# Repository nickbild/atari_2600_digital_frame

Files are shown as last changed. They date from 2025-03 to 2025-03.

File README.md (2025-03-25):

# Atari 2600 Digital Photo Frame

Turn your family photos into retro 8-bit masterpieces with this Atari 2600 digital frame. It is powered by a custom cartridge containing a Raspberry Pi Pico, so it can do a lot of other tricks as well.

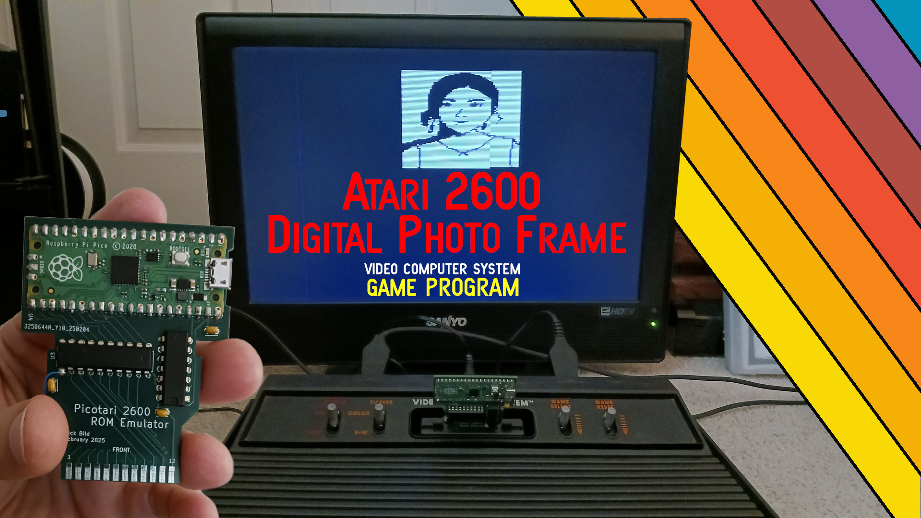
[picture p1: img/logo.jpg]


Watch the video on YouTube:
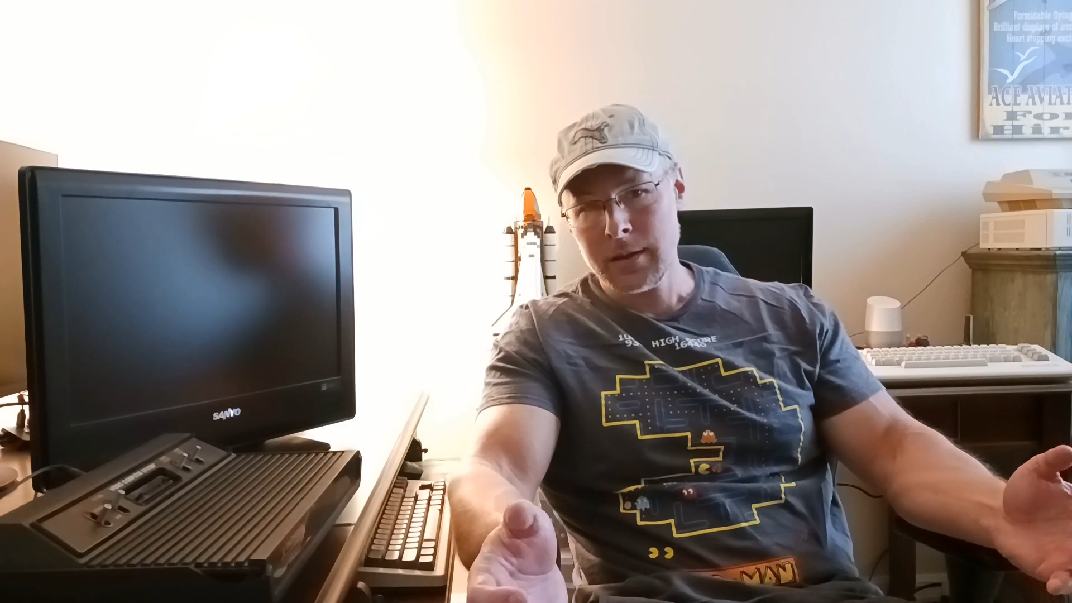
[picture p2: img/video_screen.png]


## How It Works

I recently picked up an Atari 2600 and, after repairing it (the left joystick port did not work; fortunately it turned out to be just broken pins), I wanted to do something special with it. I thought about making something like a Game Boy Camera for it (which I think is a good idea and may still do), or making a really advanced game by incorporating some modern hardware (also a good idea, but I previously made a [2600 game](https://github.com/nickbild/journey_to_xenos) and know how painful it is). In the end, I settled on a digital photo frame. The 8-bit graphics of the Atari 2600 are so beautiful (in their own special way) that it would be nice to be able to cycle through a collection of images during the day.

But without bankswitching, a cartridge can only contain 4KB of data. The largest bankswitched cartridge (that I know of, anyway), is still only 64KB, and it takes a lot of monkeying around to keep track of all of that and switch as needed — especially with the limited CPU cycles available to the programmer. Any way you slice it, you cannot store a lot of images in that space.

For this reason, I built what I call a Picotari cartridge ([gerber files](https://github.com/nickbild/atari_2600_digital_frame/tree/main/picotari_pcb)). It is a customized version of my [PicoROM ROM emulator](https://github.com/nickbild/picoROM) that has edge connectors for an Atari 2600 cartridge port, as well as supporting hardware to put the onboard Raspberry Pi Pico on the Atari's address and data busses at the right times.

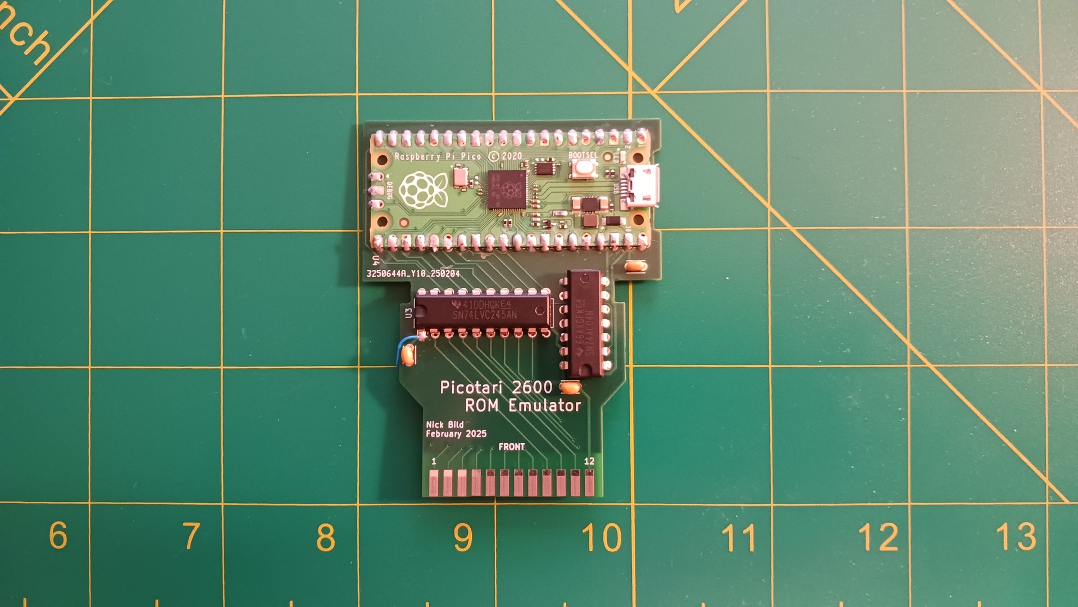
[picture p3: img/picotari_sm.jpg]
|  | 
|:--:| 
| *What bodge wire? I don't see any bodge wires.* |

With modern hardware in the mix, there are plenty of options to expand memory (and more). For my digital frame project, the path I chose only requires one byte of ROM (as far as the Atari is concerned) to display an unlimited number of images. This is made possible by addressing a specified byte each time I need the next 8 pixels to draw a player sprite. Each time that address is requested, the Picotari knows to actually look at the next address sequentially in a much larger memory space that it holds internally. In this case, I only used the Pico's onboard memory, but it would be trival to add on an SD card reader and pull from there, making gigabytes of storage possible. The Picotari code [is here](https://github.com/nickbild/atari_2600_digital_frame/blob/main/pico_rom.c).

The Atari [runs a program](https://github.com/nickbild/atari_2600_digital_frame/blob/main/showpic.asm) that displays a 64x84-pixel image. Since the Atari needs to be fed one byte at a time for display (there is no frame buffer), sequential retrieval is ideal for this application. Getting anything like a bitmap to display on the 2600 is very difficult since it was never meant to do any such thing. I made it work by using the well-known 48-pixel image trick, which uses sprite copies and vertical delays to just barely fit 6 8-bit sprites on a single scan line. To get it up to 64, I draw the first 48 pixels on one frame, then the next 16 at a position just after that on the next frame, and repeat that process *ad infinitum*. The height of the image could actually go all the way up to 192 pixels, there is no restriction on that — I just think 64x84 has a nice aspect ratio. The images must be 2 colors — there are absolutely no cycles availble to change the color registers as the image is drawn.

### Preparing the images

I started with a photo, such as this one:

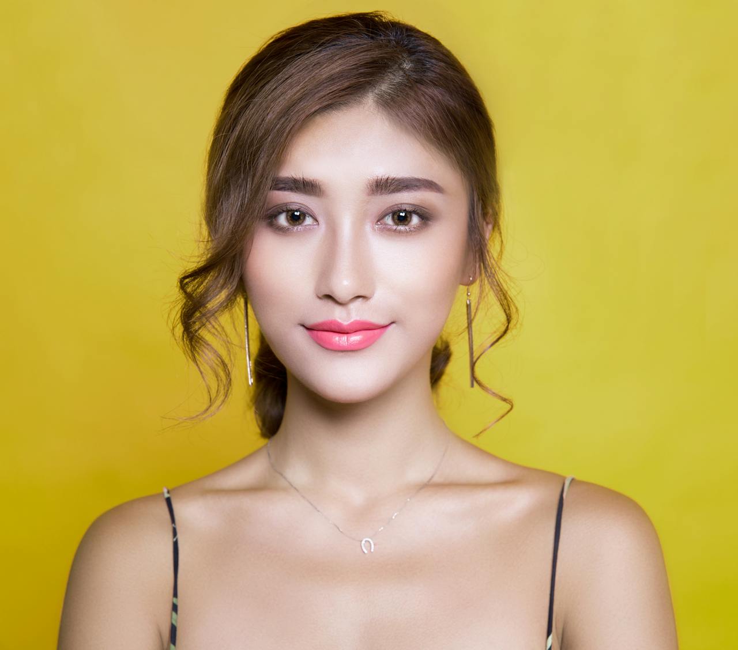
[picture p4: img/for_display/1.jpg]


Then I ran it through [Pixel It](https://giventofly.github.io/pixelit/) to help 8-bit-ify it before doing a little manual touch-up in Gimp. The results are something like this:



Next, I used this [Python script](https://github.com/nickbild/atari_2600_digital_frame/blob/main/read_img.py) to read the image data and turn it into a data strucutre that can be used by the Picotari. The Atari ROM is also turned into a data strucure using [this script](https://github.com/nickbild/atari_2600_digital_frame/blob/main/translate_bin2rom.py).

Once the Picotari is flashed with code containing this data, it only needs to be plugged into the Atari like any other cartridge. It is fully self-contained, drawing its power from the Atari.

As presently coded, each image is displayed for about 30 seconds before the next is loaded. After the last image is displayed, it will go back to the first image.

### Early fails

Before designing the Picotari PCB, I prototyped the circuit on perfboard. Even with that huge EMI shield, this version did a lot of unintentional modulating of the Atari's RF output. The wiring on the back is actually quite minimal and neat, but the on-screen image was still full of static and sometimes even rolled. Things were so bad I wasn't sure if the PCB would even do the trick, but fortunately, it cleared the noise up completely.

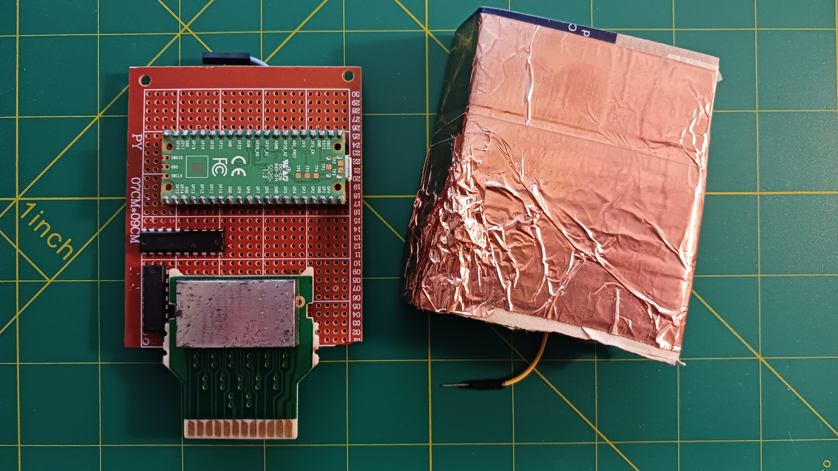
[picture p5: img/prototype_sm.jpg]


## Media

[YouTube Video](https://www.youtube.com/watch?v=uxBHm1ROvYI)

Meow do you do?

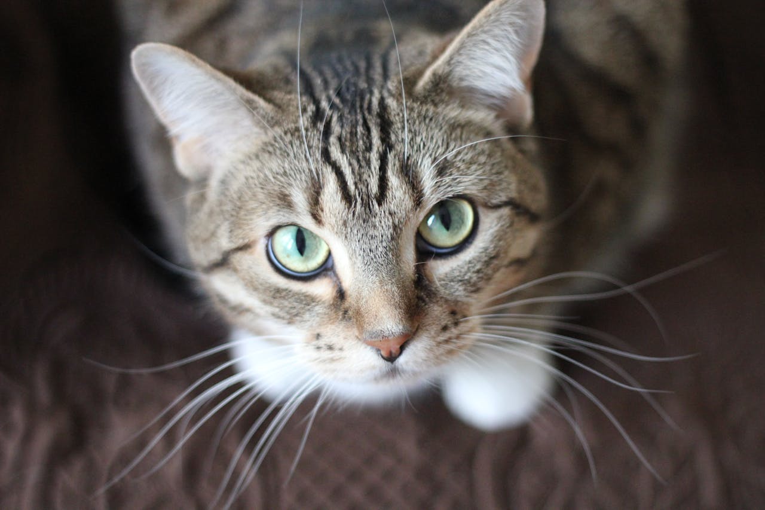
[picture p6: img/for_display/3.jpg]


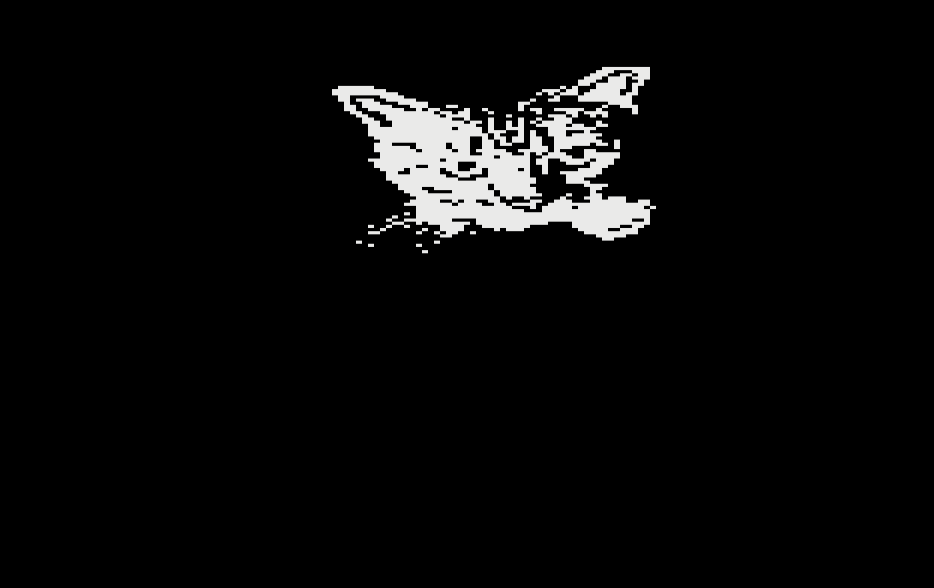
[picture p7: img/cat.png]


I sincerely apologize for turning you into Jim Morrison.

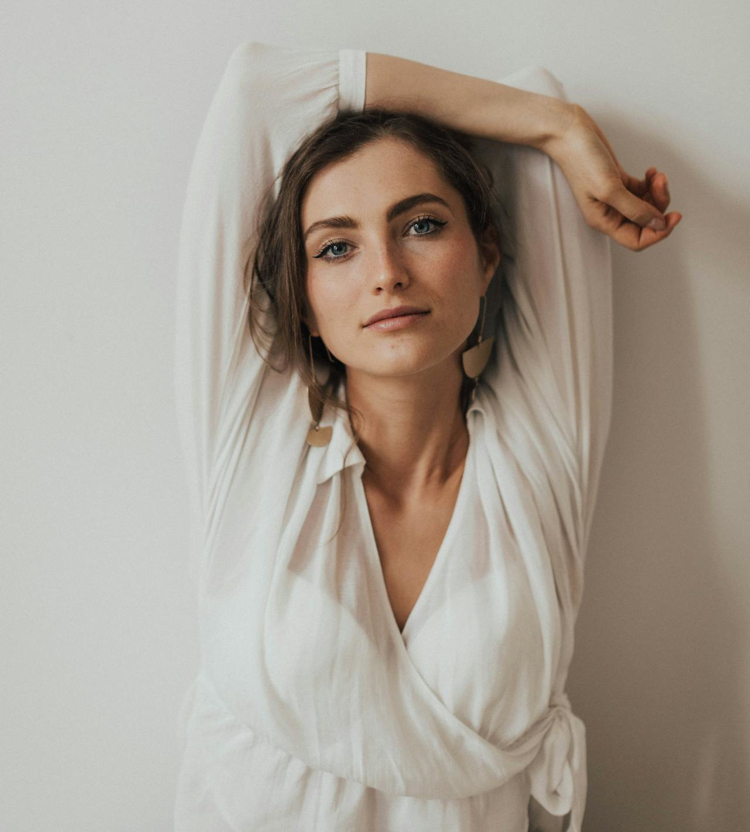
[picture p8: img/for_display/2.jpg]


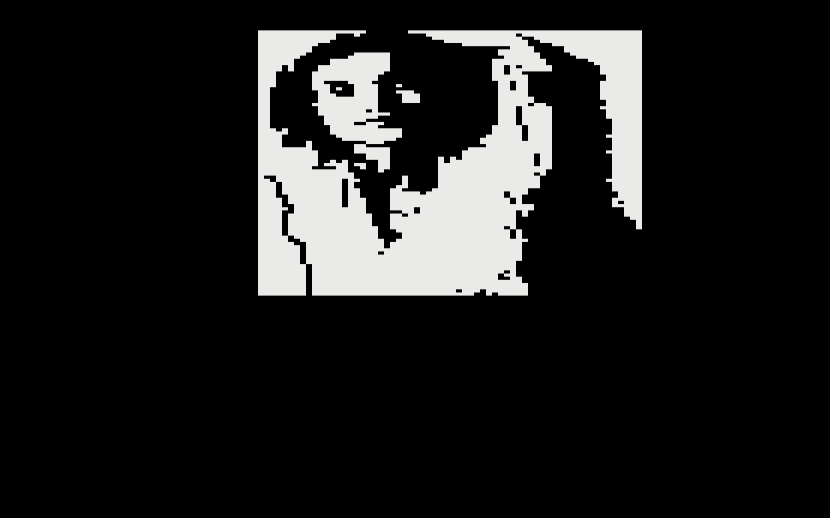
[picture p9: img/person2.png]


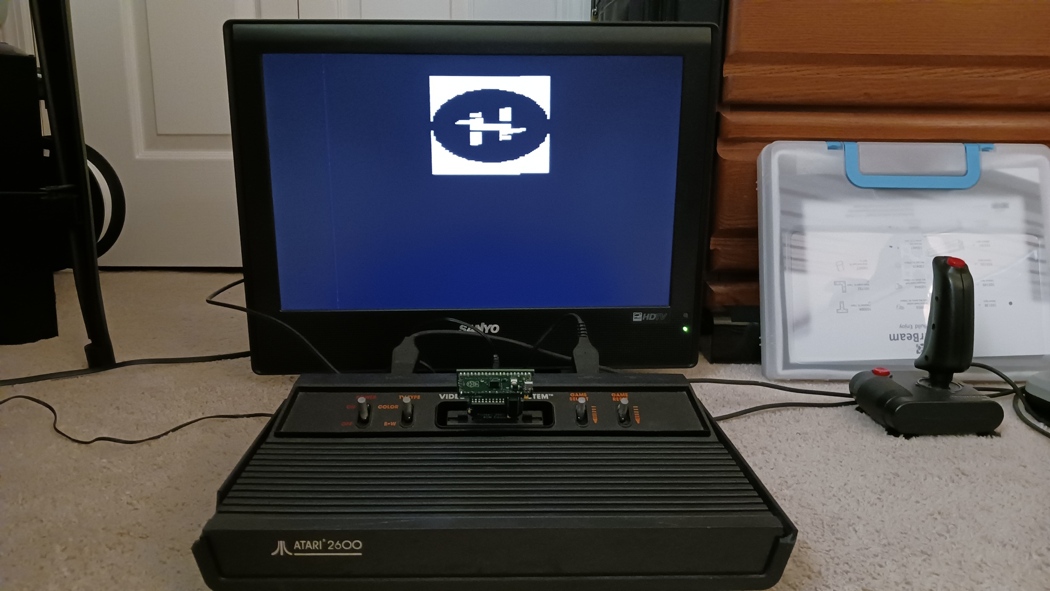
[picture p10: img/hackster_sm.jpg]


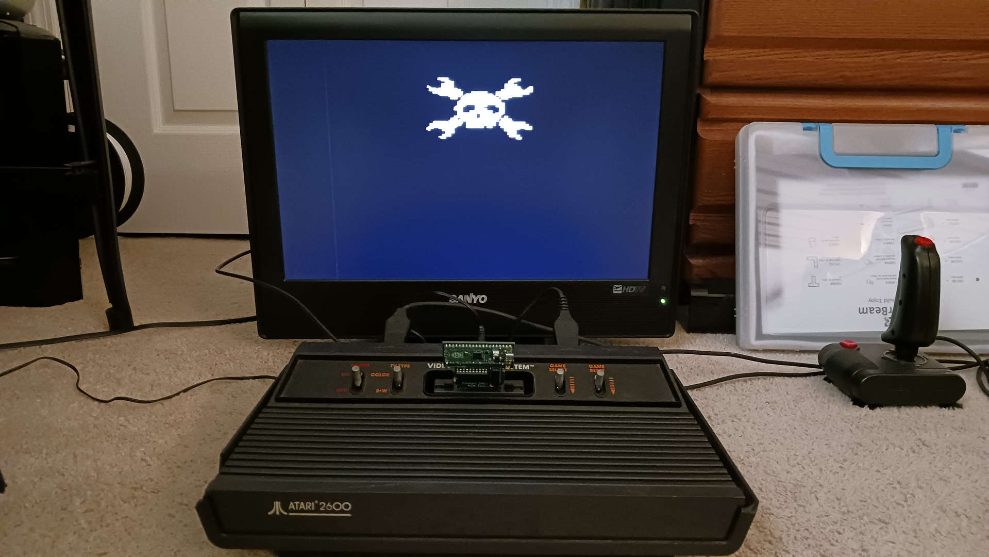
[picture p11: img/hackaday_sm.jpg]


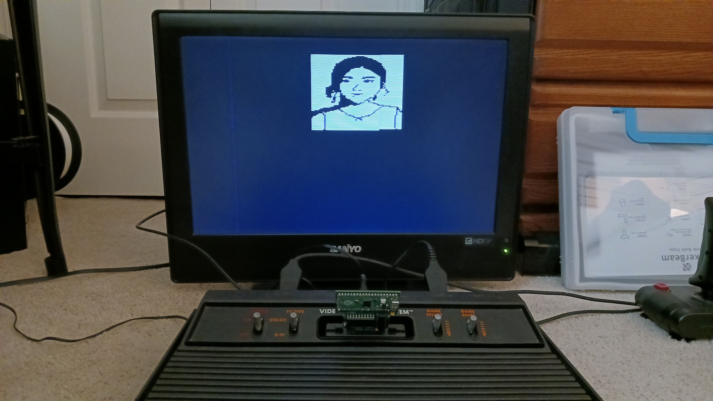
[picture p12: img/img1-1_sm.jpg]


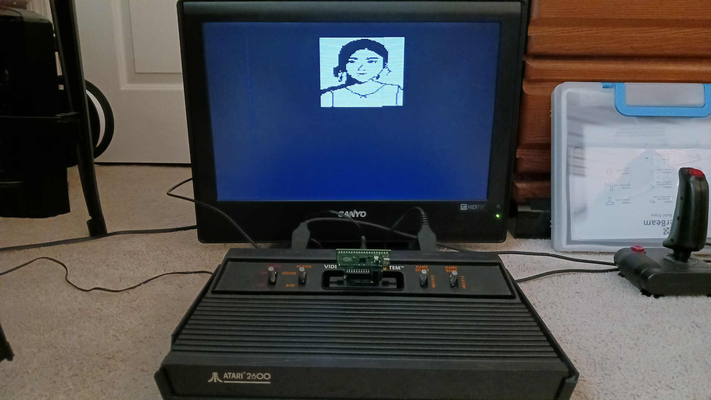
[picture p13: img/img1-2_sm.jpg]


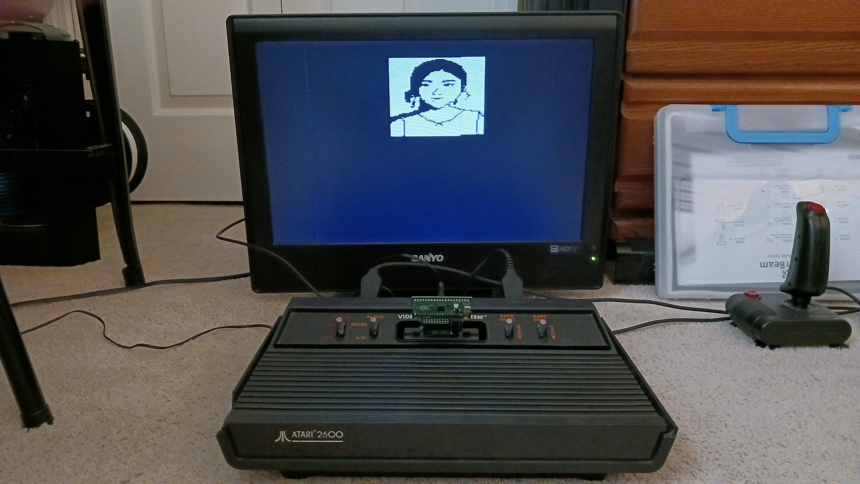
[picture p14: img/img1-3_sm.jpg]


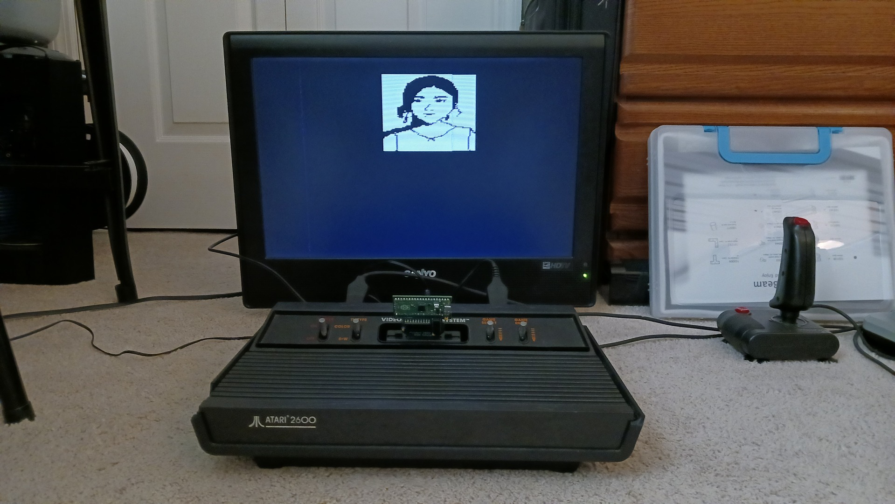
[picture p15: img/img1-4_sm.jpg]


## Bill of Materials

- 1 x Atari 2600
- 1 x Raspberry Pi Pico
- 1 x 74LVC245AN octal bus transciever
- 1 x 74AC04N hex inverter
- 3 x 0.1 uF capacitors
- 1 x Picotari 2600 Rom Emulator PCB ([gerber files](https://github.com/nickbild/atari_2600_digital_frame/tree/main/picotari_pcb))

## About the Author

[Nick A. Bild, MS](https://nickbild79.firebaseapp.com/#!/)

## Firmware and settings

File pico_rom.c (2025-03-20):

/*
* PicoROM
* Simulate a ROM chip (e.g. 28c256) with a Raspberry Pi Pico.
* Nick Bild (nick.bild@gmail.com)
* August 2021
*/

#include "pico/stdlib.h"
#include "hardware/clocks.h"
#include "hardware/vreg.h"
#include "pin_definitions.h"
#include <stdlib.h>

void setup_gpio();
int get_requested_address();
void put_data_on_bus(int);
void setup_rom_contents();

uint8_t rom_contents[32768] = {};
uint16_t img_pos;
uint16_t img_start;
uint16_t img_end;
uint16_t last_address;
uint16_t frame_counter = 0;

int main() {
    // Specify contents of emulated ROM.
    setup_rom_contents();

    // Set system clock speed.
    // 400 MHz
    vreg_set_voltage(VREG_VOLTAGE_1_30);
    set_sys_clock_pll(1600000000, 4, 1);
    
    // GPIO setup.
    setup_gpio();

    img_pos = 5000;
	img_start = 5000;
	img_end = 5671;
	last_address = 0;
	frame_counter = 0;
    
    // Continually check address lines and
    // put associated data on bus.
    while (true) {
        put_data_on_bus(get_requested_address());
    }
}

void setup_gpio() {
    // Address pins.
    gpio_init(A0);
    gpio_set_dir(A0, GPIO_IN);
    gpio_init(A1);
    gpio_set_dir(A1, GPIO_IN);
    gpio_init(A2);
    gpio_set_dir(A2, GPIO_IN);
    gpio_init(A3);
    gpio_set_dir(A3, GPIO_IN);
    gpio_init(A4);
    gpio_set_dir(A4, GPIO_IN);
    gpio_init(A5);
    gpio_set_dir(A5, GPIO_IN);
    gpio_init(A6);
    gpio_set_dir(A6, GPIO_IN);
    gpio_init(A7);
    gpio_set_dir(A7, GPIO_IN);
    gpio_init(A8);
    gpio_set_dir(A8, GPIO_IN);
    gpio_init(A9);
    gpio_set_dir(A9, GPIO_IN);
    gpio_init(A10);
    gpio_set_dir(A10, GPIO_IN);
    gpio_init(A11);
    gpio_set_dir(A11, GPIO_IN);
    gpio_init(A12);
    gpio_set_dir(A12, GPIO_IN);
    gpio_init(A13);
    gpio_set_dir(A13, GPIO_IN);
    gpio_init(A14);
    gpio_set_dir(A14, GPIO_IN);

    // Data pins.
    gpio_init(D0);
    gpio_set_dir(D0, GPIO_OUT);
    gpio_init(D1);
    gpio_set_dir(D1, GPIO_OUT);
    gpio_init(D2);
    gpio_set_dir(D2, GPIO_OUT);
    gpio_init(D3);
    gpio_set_dir(D3, GPIO_OUT);
    gpio_init(D4);
    gpio_set_dir(D4, GPIO_OUT);
    gpio_init(D5);
    gpio_set_dir(D5, GPIO_OUT);
    gpio_init(D6);
    gpio_set_dir(D6, GPIO_OUT);
    gpio_init(D7);
    gpio_set_dir(D7, GPIO_OUT);
}

int get_requested_address() {
    // Return only first 15 bits.
    return gpio_get_all() & 32767;
}

void put_data_on_bus(int address) {
    // Special handing of image data.
    if (address == 3840) {
        gpio_put_masked(8355840, rom_contents[img_pos] << 15);

		if (last_address != 3840) {
			img_pos++;
		}

		// If a full frame has been drawn...
		if (img_pos == img_end+1) {
			img_pos = img_start;

			frame_counter++;

			// Every X number of frames, show the next image.
			if (frame_counter > 1000) {
				frame_counter = 0;
				img_start = img_start + 672;
				img_end = img_end + 672;

				// If all images have been shown, start over.
				if (img_start > 7016) {
					img_start = 5000;
					img_end = 5671;
				}
			}
		}
		
		last_address = address;
        
        return;
    }

    // gpio mask = 8355840; // i.e.: 11111111000000000000000
    // Shift data 15 bits to put it in correct position to match data pin defintion.
    gpio_put_masked(8355840, rom_contents[address] << 15);
	last_address = address;
}

void setup_rom_contents() {
    // Program, starting at ROM address 0.
    rom_contents[0] = 120;
	rom_contents[1] = 216;
	rom_contents[2] = 171;
	rom_contents[3] = 0;
	rom_contents[4] = 168;
	rom_contents[5] = 202;
	rom_contents[6] = 154;
	rom_contents[7] = 72;
	rom_contents[8] = 208;
	rom_contents[9] = 251;
	rom_contents[10] = 169;
	rom_contents[11] = 14;
	rom_contents[12] = 133;
	rom_contents[13] = 2;
	rom_contents[14] = 133;
	rom_contents[15] = 0;
	rom_contents[16] = 74;
	rom_contents[17] = 208;
	rom_contents[18] = 249;
	rom_contents[19] = 169;
	rom_contents[20] = 44;
	rom_contents[21] = 141;
	rom_contents[22] = 150;
	rom_contents[23] = 2;
	rom_contents[24] = 169;
	rom_contents[25] = 55;
	rom_contents[26] = 162;
	rom_contents[27] = 0;
	rom_contents[28] = 32;
	rom_contents[29] = 254;
	rom_contents[30] = 240;
	rom_contents[31] = 169;
	rom_contents[32] = 63;
	rom_contents[33] = 162;
	rom_contents[34] = 1;
	rom_contents[35] = 32;
	rom_contents[36] = 254;
	rom_contents[37] = 240;
	rom_contents[38] = 133;
	rom_contents[39] = 2;
	rom_contents[40] = 133;
	rom_contents[41] = 42;
	rom_contents[42] = 169;
	rom_contents[43] = 1;
	rom_contents[44] = 133;
	rom_contents[45] = 37;
	rom_contents[46] = 133;
	rom_contents[47] = 38;
	rom_contents[48] = 169;
	rom_contents[49] = 3;
	rom_contents[50] = 133;
	rom_contents[51] = 4;
	rom_contents[52] = 133;
	rom_contents[53] = 5;
	rom_contents[54] = 169;
	rom_contents[55] = 15;
	rom_contents[56] = 133;
	rom_contents[57] = 6;
	rom_contents[58] = 133;
	rom_contents[59] = 7;
	rom_contents[60] = 173;
	rom_contents[61] = 132;
	rom_contents[62] = 2;
	rom_contents[63] = 208;
	rom_contents[64] = 251;
	rom_contents[65] = 133;
	rom_contents[66] = 2;
	rom_contents[67] = 133;
	rom_contents[68] = 1;
	rom_contents[69] = 160;
	rom_contents[70] = 83;
	rom_contents[71] = 132;
	rom_contents[72] = 129;
	rom_contents[73] = 133;
	rom_contents[74] = 2;
	rom_contents[75] = 173;
	rom_contents[76] = 0;
	rom_contents[77] = 255;
	rom_contents[78] = 133;
	rom_contents[79] = 27;
	rom_contents[80] = 173;
	rom_contents[81] = 0;
	rom_contents[82] = 255;
	rom_contents[83] = 133;
	rom_contents[84] = 28;
	rom_contents[85] = 173;
	rom_contents[86] = 0;
	rom_contents[87] = 255;
	rom_contents[88] = 133;
	rom_contents[89] = 27;
	rom_contents[90] = 173;
	rom_contents[91] = 0;
	rom_contents[92] = 255;
	rom_contents[93] = 170;
	rom_contents[94] = 173;
	rom_contents[95] = 0;
	rom_contents[96] = 255;
	rom_contents[97] = 133;
	rom_contents[98] = 128;
	rom_contents[99] = 173;
	rom_contents[100] = 0;
	rom_contents[101] = 255;
	rom_contents[102] = 164;
	rom_contents[103] = 128;
	rom_contents[104] = 134;
	rom_contents[105] = 28;
	rom_contents[106] = 132;
	rom_contents[107] = 27;
	rom_contents[108] = 133;
	rom_contents[109] = 28;
	rom_contents[110] = 133;
	rom_contents[111] = 27;
	rom_contents[112] = 198;
	rom_contents[113] = 129;
	rom_contents[114] = 164;
	rom_contents[115] = 129;
	rom_contents[116] = 16;
	rom_contents[117] = 211;
	rom_contents[118] = 169;
	rom_contents[119] = 0;
	rom_contents[120] = 133;
	rom_contents[121] = 28;
	rom_contents[122] = 133;
	rom_contents[123] = 27;
	rom_contents[124] = 133;
	rom_contents[125] = 28;
	rom_contents[126] = 162;
	rom_contents[127] = 109;
	rom_contents[128] = 133;
	rom_contents[129] = 2;
	rom_contents[130] = 202;
	rom_contents[131] = 208;
	rom_contents[132] = 251;
	rom_contents[133] = 169;
	rom_contents[134] = 36;
	rom_contents[135] = 141;
	rom_contents[136] = 150;
	rom_contents[137] = 2;
	rom_contents[138] = 173;
	rom_contents[139] = 132;
	rom_contents[140] = 2;
	rom_contents[141] = 208;
	rom_contents[142] = 251;
	rom_contents[143] = 169;
	rom_contents[144] = 14;
	rom_contents[145] = 133;
	rom_contents[146] = 2;
	rom_contents[147] = 133;
	rom_contents[148] = 0;
	rom_contents[149] = 74;
	rom_contents[150] = 208;
	rom_contents[151] = 249;
	rom_contents[152] = 169;
	rom_contents[153] = 44;
	rom_contents[154] = 141;
	rom_contents[155] = 150;
	rom_contents[156] = 2;
	rom_contents[157] = 169;
	rom_contents[158] = 103;
	rom_contents[159] = 162;
	rom_contents[160] = 0;
	rom_contents[161] = 32;
	rom_contents[162] = 254;
	rom_contents[163] = 240;
	rom_contents[164] = 169;
	rom_contents[165] = 111;
	rom_contents[166] = 162;
	rom_contents[167] = 1;
	rom_contents[168] = 32;
	rom_contents[169] = 254;
	rom_contents[170] = 240;
	rom_contents[171] = 133;
	rom_contents[172] = 2;
	rom_contents[173] = 133;
	rom_contents[174] = 42;
	rom_contents[175] = 169;
	rom_contents[176] = 1;
	rom_contents[177] = 133;
	rom_contents[178] = 37;
	rom_contents[179] = 133;
	rom_contents[180] = 38;
	rom_contents[181] = 169;
	rom_contents[182] = 0;
	rom_contents[183] = 133;
	rom_contents[184] = 4;
	rom_contents[185] = 133;
	rom_contents[186] = 5;
	rom_contents[187] = 169;
	rom_contents[188] = 15;
	rom_contents[189] = 133;
	rom_contents[190] = 6;
	rom_contents[191] = 133;
	rom_contents[192] = 7;
	rom_contents[193] = 173;
	rom_contents[194] = 132;
	rom_contents[195] = 2;
	rom_contents[196] = 208;
	rom_contents[197] = 251;
	rom_contents[198] = 133;
	rom_contents[199] = 2;
	rom_contents[200] = 133;
	rom_contents[201] = 1;
	rom_contents[202] = 160;
	rom_contents[203] = 83;
	rom_contents[204] = 132;
	rom_contents[205] = 129;
	rom_contents[206] = 133;
	rom_contents[207] = 2;
	rom_contents[208] = 173;
	rom_contents[209] = 0;
	rom_contents[210] = 255;
	rom_contents[211] = 133;
	rom_contents[212] = 27;
	rom_contents[213] = 173;
	rom_contents[214] = 0;
	rom_contents[215] = 255;
	rom_contents[216] = 133;
	rom_contents[217] = 28;
	rom_contents[218] = 133;
	rom_contents[219] = 27;
	rom_contents[220] = 198;
	rom_contents[221] = 129;
	rom_contents[222] = 164;
	rom_contents[223] = 129;
	rom_contents[224] = 16;
	rom_contents[225] = 236;
	rom_contents[226] = 169;
	rom_contents[227] = 0;
	rom_contents[228] = 133;
	rom_contents[229] = 28;
	rom_contents[230] = 133;
	rom_contents[231] = 27;
	rom_contents[232] = 133;
	rom_contents[233] = 28;
	rom_contents[234] = 162;
	rom_contents[235] = 109;
	rom_contents[236] = 133;
	rom_contents[237] = 2;
	rom_contents[238] = 202;
	rom_contents[239] = 208;
	rom_contents[240] = 251;
	rom_contents[241] = 169;
	rom_contents[242] = 36;
	rom_contents[243] = 141;
	rom_contents[244] = 150;
	rom_contents[245] = 2;
	rom_contents[246] = 173;
	rom_contents[247] = 132;
	rom_contents[248] = 2;
	rom_contents[249] = 208;
	rom_contents[250] = 251;
	rom_contents[251] = 76;
	rom_contents[252] = 10;
	rom_contents[253] = 240;
	rom_contents[254] = 133;
	rom_contents[255] = 2;
	rom_contents[256] = 36;
	rom_contents[257] = 0;
	rom_contents[258] = 56;
	rom_contents[259] = 233;
	rom_contents[260] = 15;
	rom_contents[261] = 176;
	rom_contents[262] = 252;
	rom_contents[263] = 73;
	rom_contents[264] = 7;
	rom_contents[265] = 10;
	rom_contents[266] = 10;
	rom_contents[267] = 10;
	rom_contents[268] = 10;
	rom_contents[269] = 149;
	rom_contents[270] = 16;
	rom_contents[271] = 149;
	rom_contents[272] = 32;
	rom_contents[273] = 96;
	rom_contents[274] = 255;
	rom_contents[275] = 255;
	rom_contents[276] = 255;
	rom_contents[277] = 255;
	rom_contents[278] = 255;
	rom_contents[279] = 255;
	rom_contents[280] = 255;
	rom_contents[281] = 255;
	rom_contents[282] = 255;
	rom_contents[283] = 255;
	rom_contents[284] = 255;
	rom_contents[285] = 255;
	rom_contents[286] = 255;
	rom_contents[287] = 255;
	rom_contents[288] = 255;
	rom_contents[289] = 255;
	rom_contents[290] = 255;
	rom_contents[291] = 255;
	rom_contents[292] = 255;
	rom_contents[293] = 255;
	rom_contents[294] = 255;
	rom_contents[295] = 255;
	rom_contents[296] = 255;
	rom_contents[297] = 255;
	rom_contents[298] = 255;
	rom_contents[299] = 255;
	rom_contents[300] = 255;
	rom_contents[301] = 255;
	rom_contents[302] = 255;
	rom_contents[303] = 255;
	rom_contents[304] = 255;
	rom_contents[305] = 255;
	rom_contents[306] = 255;
	rom_contents[307] = 255;
	rom_contents[308] = 255;
	rom_contents[309] = 255;
	rom_contents[310] = 255;
	rom_contents[311] = 255;
	rom_contents[312] = 255;
	rom_contents[313] = 255;
	rom_contents[314] = 255;
	rom_contents[315] = 255;
	rom_contents[316] = 255;
	rom_contents[317] = 255;
	rom_contents[318] = 255;
	rom_contents[319] = 255;
	rom_contents[320] = 255;
	rom_contents[321] = 255;
	rom_contents[322] = 255;
	rom_contents[323] = 255;
	rom_contents[324] = 255;
	rom_contents[325] = 255;
	rom_contents[326] = 255;
	rom_contents[327] = 255;
	rom_contents[328] = 255;
	rom_contents[329] = 255;
	rom_contents[330] = 255;
	rom_contents[331] = 255;
	rom_contents[332] = 255;
	rom_contents[333] = 255;
	rom_contents[334] = 255;
	rom_contents[335] = 255;
	rom_contents[336] = 255;
	rom_contents[337] = 255;
	rom_contents[338] = 255;
	rom_contents[339] = 255;
	rom_contents[340] = 255;
	rom_contents[341] = 255;
	rom_contents[342] = 255;
	rom_contents[343] = 255;
	rom_contents[344] = 255;
	rom_contents[345] = 255;
	rom_contents[346] = 255;
	rom_contents[347] = 255;
	rom_contents[348] = 255;
	rom_contents[349] = 255;
	rom_contents[350] = 255;
	rom_contents[351] = 255;
	rom_contents[352] = 255;
	rom_contents[353] = 255;
	rom_contents[354] = 255;
	rom_contents[355] = 255;
	rom_contents[356] = 255;
	rom_contents[357] = 255;
	rom_contents[358] = 255;
	rom_contents[359] = 255;
	rom_contents[360] = 255;
	rom_contents[361] = 255;
	rom_contents[362] = 255;
	rom_contents[363] = 255;
	rom_contents[364] = 255;
	rom_contents[365] = 255;
	rom_contents[366] = 255;
	rom_contents[367] = 255;
	rom_contents[368] = 255;
	rom_contents[369] = 255;
	rom_contents[370] = 255;
	rom_contents[371] = 255;
	rom_contents[372] = 255;
	rom_contents[373] = 255;
	rom_contents[374] = 255;
	rom_contents[375] = 255;
	rom_contents[376] = 255;
	rom_contents[377] = 255;
	rom_contents[378] = 255;
	rom_contents[379] = 255;
	rom_contents[380] = 255;
	rom_contents[381] = 255;
	rom_contents[382] = 255;
	rom_contents[383] = 255;
	rom_contents[384] = 255;
	rom_contents[385] = 255;
	rom_contents[386] = 255;
	rom_contents[387] = 255;
	rom_contents[388] = 255;
	rom_contents[389] = 255;
	rom_contents[390] = 255;
	rom_contents[391] = 255;
	rom_contents[392] = 255;
	rom_contents[393] = 255;
	rom_contents[394] = 255;
	rom_contents[395] = 255;
	rom_contents[396] = 255;
	rom_contents[397] = 255;
	rom_contents[398] = 255;
	rom_contents[399] = 255;
	rom_contents[400] = 255;
	rom_contents[401] = 255;
	rom_contents[402] = 255;
	rom_contents[403] = 255;
	rom_contents[404] = 255;
	rom_contents[405] = 255;
	rom_contents[406] = 255;
	rom_contents[407] = 255;
	rom_contents[408] = 255;
	rom_contents[409] = 255;
	rom_contents[410] = 255;
	rom_contents[411] = 255;
	rom_contents[412] = 255;
	rom_contents[413] = 255;
	rom_contents[414] = 255;
	rom_contents[415] = 255;
	rom_contents[416] = 255;
	rom_contents[417] = 255;
	rom_contents[418] = 255;
	rom_contents[419] = 255;
	rom_contents[420] = 255;
	rom_contents[421] = 255;
	rom_contents[422] = 255;
	rom_contents[423] = 255;
	rom_contents[424] = 255;
	rom_contents[425] = 255;
	rom_contents[426] = 255;
	rom_contents[427] = 255;
	rom_contents[428] = 255;
	rom_contents[429] = 255;
	rom_contents[430] = 255;
	rom_contents[431] = 255;
	rom_contents[432] = 255;
	rom_contents[433] = 255;
	rom_contents[434] = 255;
	rom_contents[435] = 255;
	rom_contents[436] = 255;
	rom_contents[437] = 255;
	rom_contents[438] = 255;
	rom_contents[439] = 255;
	rom_contents[440] = 255;
	rom_contents[441] = 255;
	rom_contents[442] = 255;
	rom_contents[443] = 255;
	rom_contents[444] = 255;
	rom_contents[445] = 255;
	rom_contents[446] = 255;
	rom_contents[447] = 255;
	rom_contents[448] = 255;
	rom_contents[449] = 255;
	rom_contents[450] = 255;
	rom_contents[451] = 255;
	rom_contents[452] = 255;
	rom_contents[453] = 255;
	rom_contents[454] = 255;
	rom_contents[455] = 255;
	rom_contents[456] = 255;
	rom_contents[457] = 255;
	rom_contents[458] = 255;
	rom_contents[459] = 255;
	rom_contents[460] = 255;
	rom_contents[461] = 255;
	rom_contents[462] = 255;
	rom_contents[463] = 255;
	rom_contents[464] = 255;
	rom_contents[465] = 255;
	rom_contents[466] = 255;
	rom_contents[467] = 255;
	rom_contents[468] = 255;
	rom_contents[469] = 255;
	rom_contents[470] = 255;
	rom_contents[471] = 255;
	rom_contents[472] = 255;
	rom_contents[473] = 255;
	rom_contents[474] = 255;
	rom_contents[475] = 255;
	rom_contents[476] = 255;
	rom_contents[477] = 255;
	rom_contents[478] = 255;
	rom_contents[479] = 255;
	rom_contents[480] = 255;
	rom_contents[481] = 255;
	rom_contents[482] = 255;
	rom_contents[483] = 255;
	rom_contents[484] = 255;
	rom_contents[485] = 255;
	rom_contents[486] = 255;
	rom_contents[487] = 255;
	rom_contents[488] = 255;
	rom_contents[489] = 255;
	rom_contents[490] = 255;
	rom_contents[491] = 255;
	rom_contents[492] = 255;
	rom_contents[493] = 255;
	rom_contents[494] = 255;
	rom_contents[495] = 255;
	rom_contents[496] = 255;
	rom_contents[497] = 255;
	rom_contents[498] = 255;
	rom_contents[499] = 255;
	rom_contents[500] = 255;
	rom_contents[501] = 255;
	rom_contents[502] = 255;
	rom_contents[503] = 255;
	rom_contents[504] = 255;
	rom_contents[505] = 255;
	rom_contents[506] = 255;
	rom_contents[507] = 255;
	rom_contents[508] = 255;
	rom_contents[509] = 255;
	rom_contents[510] = 255;
	rom_contents[511] = 255;
	rom_contents[512] = 255;
	rom_contents[513] = 255;
	rom_contents[514] = 255;
	rom_contents[515] = 255;
	rom_contents[516] = 255;
	rom_contents[517] = 255;
	rom_contents[518] = 255;
	rom_contents[519] = 255;
	rom_contents[520] = 255;
	rom_contents[521] = 255;
	rom_contents[522] = 255;
	rom_contents[523] = 255;
	rom_contents[524] = 255;
	rom_contents[525] = 255;
	rom_contents[526] = 255;
	rom_contents[527] = 255;
	rom_contents[528] = 255;
	rom_contents[529] = 255;
	rom_contents[530] = 255;
	rom_contents[531] = 255;
	rom_contents[532] = 255;
	rom_contents[533] = 255;
	rom_contents[534] = 255;
	rom_contents[535] = 255;
	rom_contents[536] = 255;
	rom_contents[537] = 255;
	rom_contents[538] = 255;
	rom_contents[539] = 255;
	rom_contents[540] = 255;
	rom_contents[541] = 255;
	rom_contents[542] = 255;
	rom_contents[543] = 255;
	rom_contents[544] = 255;
	rom_contents[545] = 255;
	rom_contents[546] = 255;
	rom_contents[547] = 255;
	rom_contents[548] = 255;
	rom_contents[549] = 255;
	rom_contents[550] = 255;
	rom_contents[551] = 255;
	rom_contents[552] = 255;
	rom_contents[553] = 255;
	rom_contents[554] = 255;
	rom_contents[555] = 255;
	rom_contents[556] = 255;
	rom_contents[557] = 255;
	rom_contents[558] = 255;
	rom_contents[559] = 255;
	rom_contents[560] = 255;
	rom_contents[561] = 255;
	rom_contents[562] = 255;
	rom_contents[563] = 255;
	rom_contents[564] = 255;
	rom_contents[565] = 255;
	rom_contents[566] = 255;
	rom_contents[567] = 255;
	rom_contents[568] = 255;
	rom_contents[569] = 255;
	rom_contents[570] = 255;
	rom_contents[571] = 255;
	rom_contents[572] = 255;
	rom_contents[573] = 255;
	rom_contents[574] = 255;
	rom_contents[575] = 255;
	rom_contents[576] = 255;
	rom_contents[577] = 255;
	rom_contents[578] = 255;
	rom_contents[579] = 255;
	rom_contents[580] = 255;
	rom_contents[581] = 255;
	rom_contents[582] = 255;
	rom_contents[583] = 255;
	rom_contents[584] = 255;
	rom_contents[585] = 255;
	rom_contents[586] = 255;
	rom_contents[587] = 255;
	rom_contents[588] = 255;
	rom_contents[589] = 255;
	rom_contents[590] = 255;
	rom_contents[591] = 255;
	rom_contents[592] = 255;
	rom_contents[593] = 255;
	rom_contents[594] = 255;
	rom_contents[595] = 255;
	rom_contents[596] = 255;
	rom_contents[597] = 255;
	rom_contents[598] = 255;
	rom_contents[599] = 255;
	rom_contents[600] = 255;
	rom_contents[601] = 255;
	rom_contents[602] = 255;
	rom_contents[603] = 255;
	rom_contents[604] = 255;
	rom_contents[605] = 255;
	rom_contents[606] = 255;
	rom_contents[607] = 255;
	rom_contents[608] = 255;
	rom_contents[609] = 255;
	rom_contents[610] = 255;
	rom_contents[611] = 255;
	rom_contents[612] = 255;
	rom_contents[613] = 255;
	rom_contents[614] = 255;
	rom_contents[615] = 255;
	rom_contents[616] = 255;
	rom_contents[617] = 255;
	rom_contents[618] = 255;
	rom_contents[619] = 255;
	rom_contents[620] = 255;
	rom_contents[621] = 255;
	rom_contents[622] = 255;
	rom_contents[623] = 255;
	rom_contents[624] = 255;
	rom_contents[625] = 255;
	rom_contents[626] = 255;
	rom_contents[627] = 255;
	rom_contents[628] = 255;
	rom_contents[629] = 255;
	rom_contents[630] = 255;
	rom_contents[631] = 255;
	rom_contents[632] = 255;
	rom_contents[633] = 255;
	rom_contents[634] = 255;
	rom_contents[635] = 255;
	rom_contents[636] = 255;
	rom_contents[637] = 255;
	rom_contents[638] = 255;
	rom_contents[639] = 255;
	rom_contents[640] = 255;
	rom_contents[641] = 255;
	rom_contents[642] = 255;
	rom_contents[643] = 255;
	rom_contents[644] = 255;
	rom_contents[645] = 255;
	rom_contents[646] = 255;
	rom_contents[647] = 255;
	rom_contents[648] = 255;
	rom_contents[649] = 255;
	rom_contents[650] = 255;
	rom_contents[651] = 255;
	rom_contents[652] = 255;
	rom_contents[653] = 255;
	rom_contents[654] = 255;
	rom_contents[655] = 255;
	rom_contents[656] = 255;
	rom_contents[657] = 255;
	rom_contents[658] = 255;
	rom_contents[659] = 255;
	rom_contents[660] = 255;
	rom_contents[661] = 255;
	rom_contents[662] = 255;
	rom_contents[663] = 255;
	rom_contents[664] = 255;
	rom_contents[665] = 255;
	rom_contents[666] = 255;
	rom_contents[667] = 255;
	rom_contents[668] = 255;
	rom_contents[669] = 255;
	rom_contents[670] = 255;
	rom_contents[671] = 255;
	rom_contents[672] = 255;
	rom_contents[673] = 255;
	rom_contents[674] = 255;
	rom_contents[675] = 255;
	rom_contents[676] = 255;
	rom_contents[677] = 255;
	rom_contents[678] = 255;
	rom_contents[679] = 255;
	rom_contents[680] = 255;
	rom_contents[681] = 255;
	rom_contents[682] = 255;
	rom_contents[683] = 255;
	rom_contents[684] = 255;
	rom_contents[685] = 255;
	rom_contents[686] = 255;
	rom_contents[687] = 255;
	rom_contents[688] = 255;
	rom_contents[689] = 255;
	rom_contents[690] = 255;
	rom_contents[691] = 255;
	rom_contents[692] = 255;
	rom_contents[693] = 255;
	rom_contents[694] = 255;
	rom_contents[695] = 255;
	rom_contents[696] = 255;
	rom_contents[697] = 255;
	rom_contents[698] = 255;
	rom_contents[699] = 255;
	rom_contents[700] = 255;
	rom_contents[701] = 255;
	rom_contents[702] = 255;
	rom_contents[703] = 255;
	rom_contents[704] = 255;
	rom_contents[705] = 255;
	rom_contents[706] = 255;
	rom_contents[707] = 255;
	rom_contents[708] = 255;
	rom_contents[709] = 255;
	rom_contents[710] = 255;
	rom_contents[711] = 255;
	rom_contents[712] = 255;
	rom_contents[713] = 255;
	rom_contents[714] = 255;
	rom_contents[715] = 255;
	rom_contents[716] = 255;
	rom_contents[717] = 255;
	rom_contents[718] = 255;
	rom_contents[719] = 255;
	rom_contents[720] = 255;
	rom_contents[721] = 255;
	rom_contents[722] = 255;
	rom_contents[723] = 255;
	rom_contents[724] = 255;
	rom_contents[725] = 255;
	rom_contents[726] = 255;
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

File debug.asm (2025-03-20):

; Nick Bild
; January 2025
; nick.bild@gmail.com
;
; This code makes use of the well-known 48-pixel image trick, and borrows from the
; implementation published at "Dr Boo's Woodgrain Wizadry":
; https://www.taswegian.com/WoodgrainWizard/tiki-index.php?page=48-pixel-Image-Routine

    processor 6502
    
    include "vcs.h"
    include "macro.h"

HEIGHT = 84 - 1


    SEG.U VARS
    ORG $80
Temp            ds 1
ImageHeightCnt     ds 1


   SEG CODE
   ORG $F000
Start:
   CLEAN_START

NextFrame
	VERTICAL_SYNC
    lda #44
    sta TIM64T

    lda #55
    ldx #0
    jsr SetHorizPos
    lda #63
    ldx #1
    jsr SetHorizPos
    sta WSYNC
    sta HMOVE
    lda #1
    sta VDELP0
    sta VDELP1
    lda #3
    sta NUSIZ0
    sta NUSIZ1
    lda #$0F
    sta COLUP0
    sta COLUP1

; VBLANK
WaitVBlank
    lda INTIM
    bne WaitVBlank
    sta WSYNC
    sta VBLANK

    ldy #HEIGHT
    sty ImageHeightCnt
BigGraphicLoop
    sta WSYNC           ; 3     (0)
    lda sprite0,y          ; 4     (4)
    sta GRP0            ; 3     (7)   
    lda sprite1,y          ; 4     (11)
    sta GRP1            ; 3     (14)   
    lda sprite2,y          ; 4     (18)
    sta GRP0            ; 3     (21)   
    lda sprite3,y          ; 4     (25*)   
    tax                 ; 2     (27)    
    lda sprite4,y          ; 4     (31)
    sta Temp            ; 3     (34)
    lda sprite5,y         ; 4     (38) 
    ldy Temp            ; 3     (41)

    stx GRP1            ; 3     (44)    
    sty GRP0            ; 3     (47)    
    sta GRP1            ; 3     (50)    
    sta GRP0            ; 3     (53)    
    dec ImageHeightCnt     ; 5     (58)
    ldy ImageHeightCnt     ; 3     (61)
    bpl BigGraphicLoop  ; 2/3   (64)


    lda #0
    sta GRP1
    sta GRP0
    sta GRP1    

    ldx #(192-HEIGHT)
VSLoop
    sta WSYNC
    dex
    bne VSLoop

SetupOS
    lda #36
    sta TIM64T

; Overscan            
WaitOverscan
    lda INTIM
    bne WaitOverscan


; Pass 2
	VERTICAL_SYNC
    lda #44
    sta TIM64T

    lda #103
    ldx #0
    jsr SetHorizPos
    lda #111
    ldx #1
    jsr SetHorizPos
    sta WSYNC
    sta HMOVE
    lda #1
    sta VDELP0
    sta VDELP1
    lda #0
    sta NUSIZ0
    sta NUSIZ1
    lda #$0F
    sta COLUP0
    sta COLUP1

; VBLANK
WaitVBlank2
    lda INTIM
    bne WaitVBlank2
    sta WSYNC
    sta VBLANK

    ldy #HEIGHT
    sty ImageHeightCnt
BigGraphicLoop2
    sta WSYNC           ; 3     (0)
    lda sprite6,y          ; 4     (4)
    sta GRP0            ; 3     (7)   
    lda sprite7,y          ; 4     (11)
    sta GRP1            ; 3     (14)
    sta GRP0
    
    dec ImageHeightCnt     ; 5  
    ldy ImageHeightCnt     ; 3 
    bpl BigGraphicLoop2  ; 2/3 


    lda #0
    sta GRP1
    sta GRP0
    sta GRP1  

    ldx #(192-HEIGHT)
VSLoop2
    sta WSYNC
    dex
    bne VSLoop2

SetupOS2
    lda #36
    sta TIM64T

; Overscan            
WaitOverscan2
    lda INTIM
    bne WaitOverscan2

    
    jmp NextFrame


SetHorizPos
    sta WSYNC
    bit 0
    sec
DivideLoop
    sbc #15
    bcs DivideLoop
    eor #7
    asl
    asl
    asl
    asl
    sta RESP0,x
    sta HMP0,x
    rts

	align 256
sprite7
	.byte 0
	.byte 0
	.byte 0
	.byte 0
	.byte 0
	.byte 0
	.byte 0
	.byte 0
	.byte 0
	.byte 0
	.byte 0
	.byte 0
	.byte 0
	.byte 0
	.byte 0
	.byte 0
	.byte 0
	.byte 0
	.byte 0
	.byte 0
	.byte 0
	.byte 0
	.byte 0
	.byte 0
	.byte 0
	.byte 0
	.byte 0
	.byte 0
	.byte 0
	.byte 128
	.byte 0
	.byte 0
	.byte 0
	.byte 0
	.byte 0
	.byte 0
	.byte 0
	.byte 0
	.byte 0
	.byte 0
	.byte 0
	.byte 0
	.byte 0
	.byte 0
	.byte 0
	.byte 0
	.byte 0
	.byte 0
	.byte 0
	.byte 0
	.byte 0
	.byte 0
	.byte 0
	.byte 0
	.byte 0
	.byte 0
	.byte 0
	.byte 0
	.byte 0
	.byte 0
	.byte 0
	.byte 0
	.byte 0
	.byte 0
	.byte 0
	.byte 0
	.byte 0
	.byte 0
	.byte 0
	.byte 0
	.byte 0
	.byte 0
	.byte 0
	.byte 0
	.byte 0
	.byte 0
	.byte 0
	.byte 0
	.byte 0
	.byte 0
	.byte 0
	.byte 0
	.byte 0
	.byte 0
sprite6
	.byte 0
	.byte 0
	.byte 0
	.byte 0
	.byte 0
	.byte 0
	.byte 0
	.byte 0
	.byte 0
	.byte 0
	.byte 0
	.byte 0
	.byte 0
	.byte 0
	.byte 0
	.byte 0
	.byte 0
	.byte 0
	.byte 0
	.byte 192
	.byte 240
	.byte 252
	.byte 156
	.byte 230
	.byte 255
	.byte 249
	.byte 255
	.byte 255
	.byte 255
	.byte 254
	.byte 255
	.byte 243
	.byte 112
	.byte 0
	.byte 0
	.byte 0
	.byte 128
	.byte 0
	.byte 0
	.byte 0
	.byte 0
	.byte 0
	.byte 128
	.byte 192
	.byte 192
	.byte 224
	.byte 224
	.byte 0
	.byte 32
	.byte 160
	.byte 32
	.byte 0
	.byte 0
	.byte 0
	.byte 0
	.byte 128
	.byte 0
	.byte 0
	.byte 128
	.byte 132
	.byte 4
	.byte 156
	.byte 120
	.byte 248
	.byte 248
	.byte 236
	.byte 228
	.byte 244
	.byte 246
	.byte 114
	.byte 119
	.byte 155
	.byte 199
	.byte 255
	.byte 0
	.byte 0
	.byte 0
	.byte 0
	.byte 0
	.byte 0
	.byte 0
	.byte 0
	.byte 0
	.byte 0
sprite5
	.byte 0
	.byte 0
	.byte 0
	.byte 0
	.byte 0
	.byte 0
	.byte 0
	.byte 0
	.byte 0
	.byte 0
	.byte 0
	.byte 0
	.byte 0
	.byte 0
	.byte 0
	.byte 0
	.byte 0
	.byte 0
	.byte 0
	.byte 0
	.byte 1
	.byte 7
	.byte 15
	.byte 31
	.byte 31
	.byte 255
	.byte 255
	.byte 255
	.byte 255
	.byte 239
	.byte 255
	.byte 227
	.byte 71
	.byte 35
	.byte 2
	.byte 3
	.byte 7
	.byte 60
	.byte 56
	.byte 62
	.byte 127
	.byte 15
	.byte 3
	.byte 59
	.byte 125
	.byte 231
	.byte 199
	.byte 134
	.byte 224
	.byte 253
	.byte 255
	.byte 254
	.byte 223
	.byte 196
	.byte 254
	.byte 217
	.byte 225
	.byte 224
	.byte 210
	.byte 55
	.byte 249
	.byte 0
	.byte 0
	.byte 143
	.byte 143
	.byte 119
	.byte 179
	.byte 81
	.byte 13
	.byte 14
	.byte 7
	.byte 3
	.byte 1
	.byte 0
	.byte 0
	.byte 0
	.byte 0
	.byte 0
	.byte 0
	.byte 0
	.byte 0
	.byte 0
	.byte 0
	.byte 0
	align 256
sprite4
	.byte 0
	.byte 0
	.byte 0
	.byte 0
	.byte 0
	.byte 0
	.byte 0
	.byte 0
	.byte 0
	.byte 0
	.byte 0
	.byte 0
	.byte 0
	.byte 0
	.byte 0
	.byte 0
	.byte 0
	.byte 0
	.byte 0
	.byte 0
	.byte 0
	.byte 0
	.byte 224
	.byte 240
	.byte 254
	.byte 255
	.byte 255
	.byte 255
	.byte 227
	.byte 139
	.byte 121
	.byte 12
	.byte 144
	.byte 252
	.byte 248
	.byte 248
	.byte 240
	.byte 248
	.byte 248
	.byte 240
	.byte 242
	.byte 210
	.byte 242
	.byte 246
	.byte 246
	.byte 243
	.byte 149
	.byte 62
	.byte 14
	.byte 140
	.byte 108
	.byte 108
	.byte 41
	.byte 41
	.byte 225
	.byte 167
	.byte 171
	.byte 36
	.byte 129
	.byte 4
	.byte 44
	.byte 32
	.byte 48
	.byte 9
	.byte 0
	.byte 5
	.byte 3
	.byte 0
	.byte 0
	.byte 0
	.byte 0
	.byte 0
	.byte 0
	.byte 0
	.byte 0
	.byte 0
	.byte 0
	.byte 0
	.byte 0
	.byte 0
	.byte 0
	.byte 0
	.byte 0
	.byte 0
sprite3
	.byte 0
	.byte 0
	.byte 0
	.byte 0
	.byte 0
	.byte 0
	.byte 0
	.byte 0
	.byte 0
	.byte 0
	.byte 0
	.byte 0
	.byte 0
	.byte 0
	.byte 0
	.byte 0
	.byte 0
	.byte 0
	.byte 0
	.byte 0
	.byte 0
	.byte 32
	.byte 130
	.byte 143
	.byte 223
	.byte 31
	.byte 255
	.byte 255
	.byte 255
	.byte 255
	.byte 243
	.byte 102
	.byte 254
	.byte 253
	.byte 253
	.byte 251
	.byte 251
	.byte 255
	.byte 31
	.byte 199
	.byte 247
	.byte 55
	.byte 31
	.byte 31
	.byte 255
	.byte 253
	.byte 207
	.byte 223
	.byte 204
	.byte 205
	.byte 205
	.byte 203
	.byte 250
	.byte 247
	.byte 244
	.byte 228
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

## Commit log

2025-02-13 Initial commit.
    [2600cart-B_Cu.gbl, 2600cart-B_Mask.gbs, 2600cart-B_Paste.gbp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]
2025-03-20 Convenience script for assembly.
